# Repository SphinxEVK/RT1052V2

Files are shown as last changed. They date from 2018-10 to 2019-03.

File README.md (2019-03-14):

# RT1052V2

**SphinxEVK**是由SphinxEVK项目成员[StackYuan](https://github.com/StackYuan)设计的，基于I.MXRT1052系列MCU的核心板。板上关键信号(SDRAM, nor flash, sd card)均设计了等长，使用了4-layer，4mil/4mil(线宽/线间距)，直径8mil/14mil(孔/带焊环)的生产工艺，可以被当前主流PCB打样厂生产。

注: 

> 开发板设计了严格的上电时序和电源域，同时兼容RT1052 A0和A1版本。
> 
> 为了减小体积，开发板使用78mil/2.00mm排针设计。如调试飞线感到不便，工程下也提供了标准100mil/2.54mm的IO拓展板：**SphinxEVK_ExtIO.PcbDoc**。

---

**板上资源：**

> 1.预留QSPI nor flash/Hyperflash双焊盘
> 
> 2.预留SDRAM焊盘
> 
> 3.RGB565 CSI接口(异面兼容[龙邱MT9V034](https://item.taobao.com/item.htm?id=562070292609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))
> 
> 4.RGB565 DSI接口
> 
> 5.KSZ8081 ENET PHY
> 
> 6.引出Micro USB(**USB1**) 
> 
> 7.引出UART(**LPUART1**)
> 
> 8.引出SWD(带RST)
> 
> 9.引出SDIO(TF slot)
> 
> 10.引出所有非关键IO

---
**勘误：**

> 1.使用LQ神眼摄像头时，由于IIC线序错误，故使用软件IIC进行初始化
> 
> 2.SD卡可能会出现枚举失败问题，原因是进入高速模式时，主芯片NVCC_SDIO脚不能完成3.3V->1.8V电压的切换。建议暂使用低速模式。
> 
> 3.UART1 RXD未设置上拉，可能在进行ISP模式时由于RT的内部bootloader检测失误，造成USB下载模式不能进入。
> 
---
**SphinxEVK实物图**



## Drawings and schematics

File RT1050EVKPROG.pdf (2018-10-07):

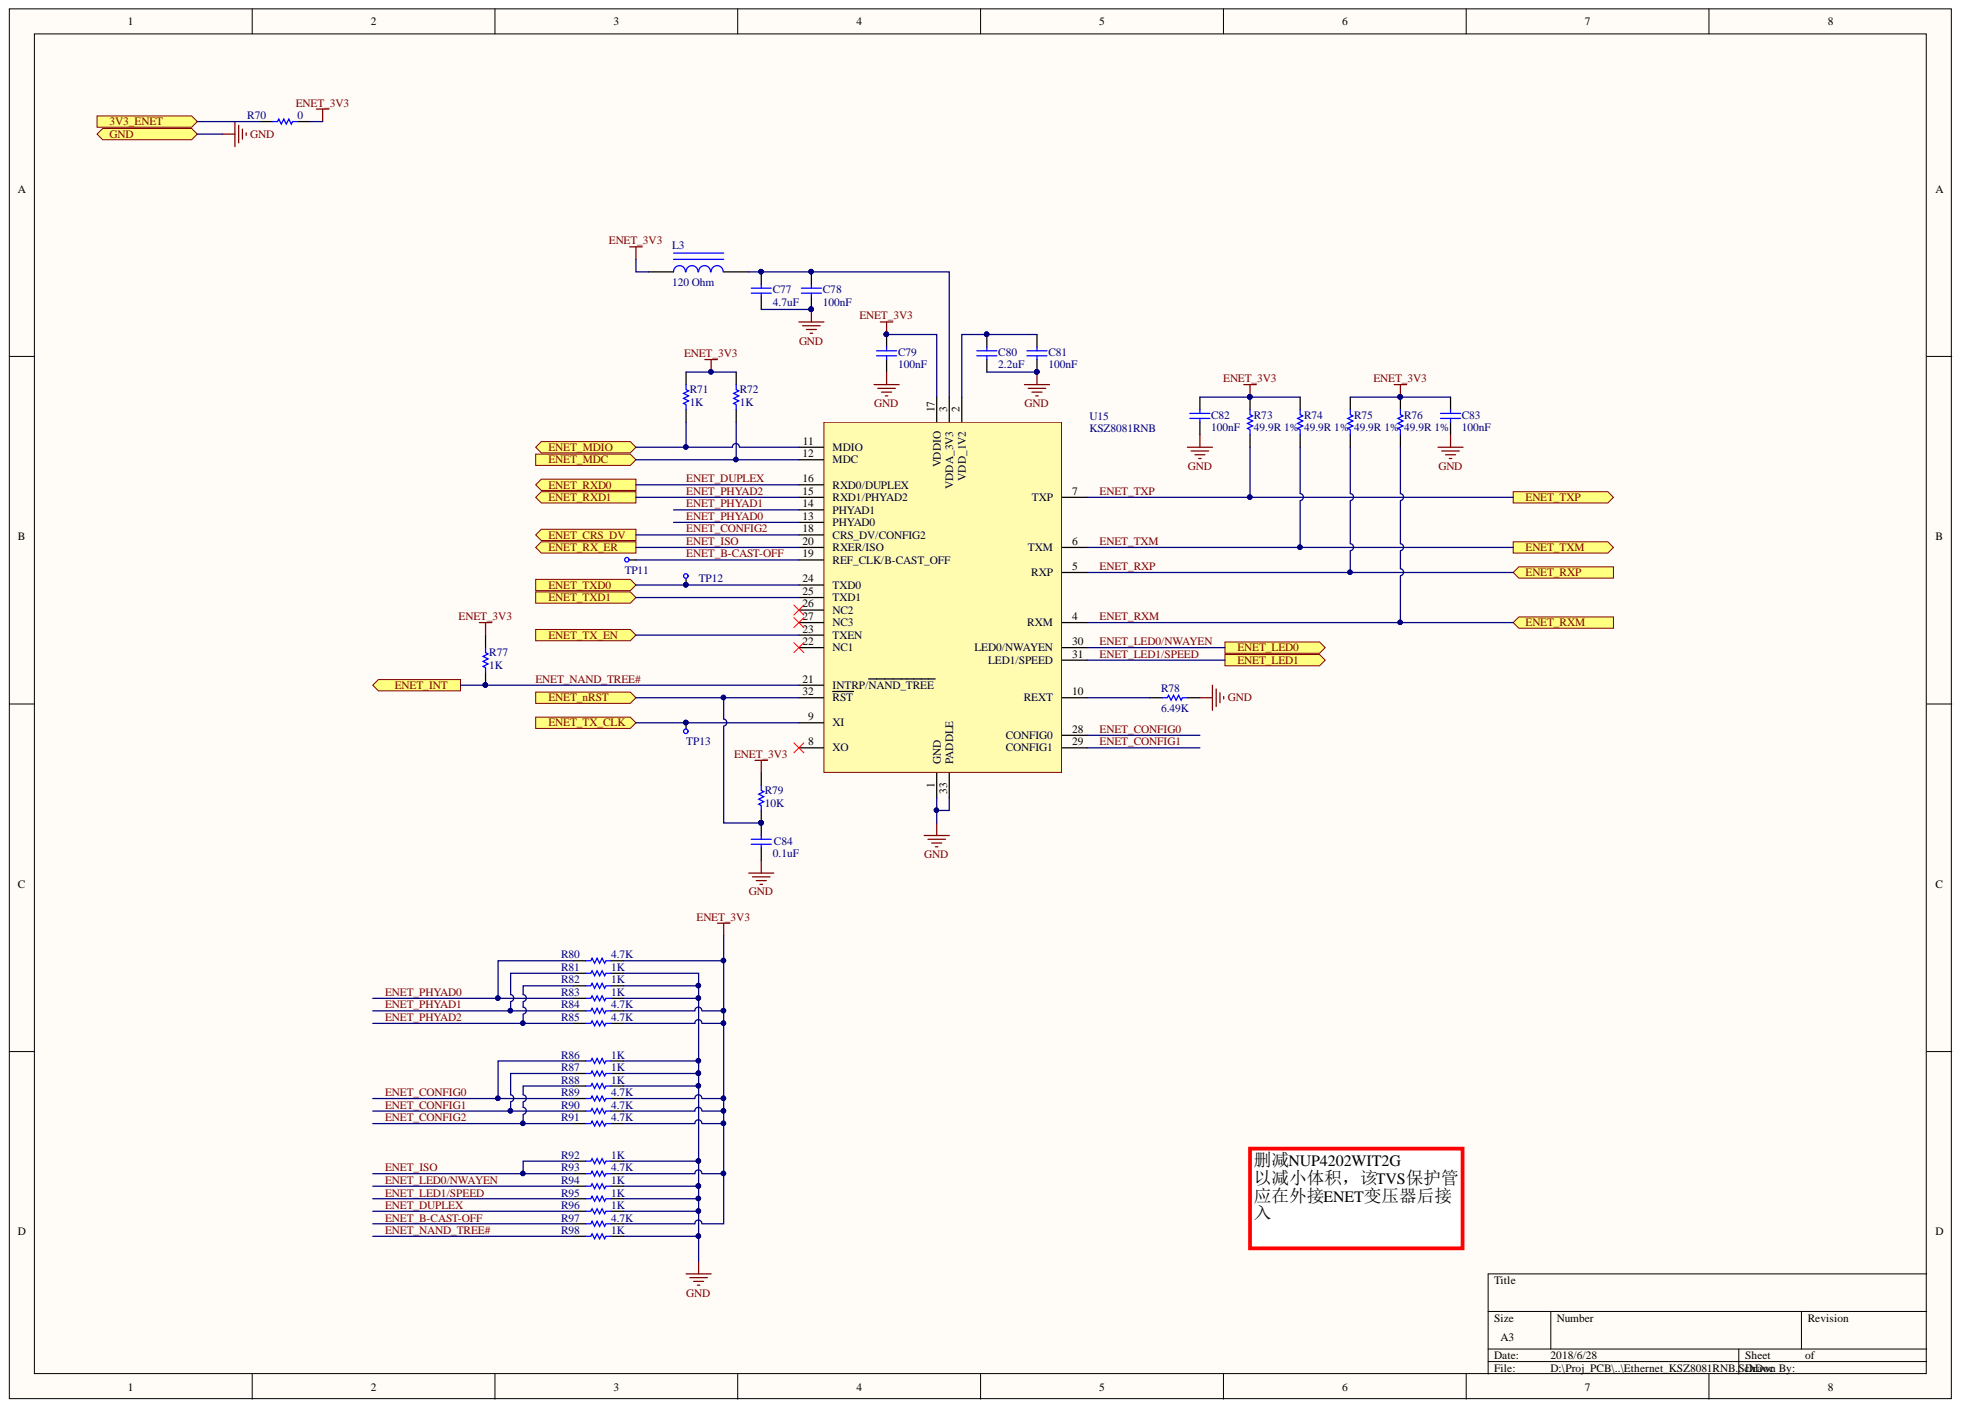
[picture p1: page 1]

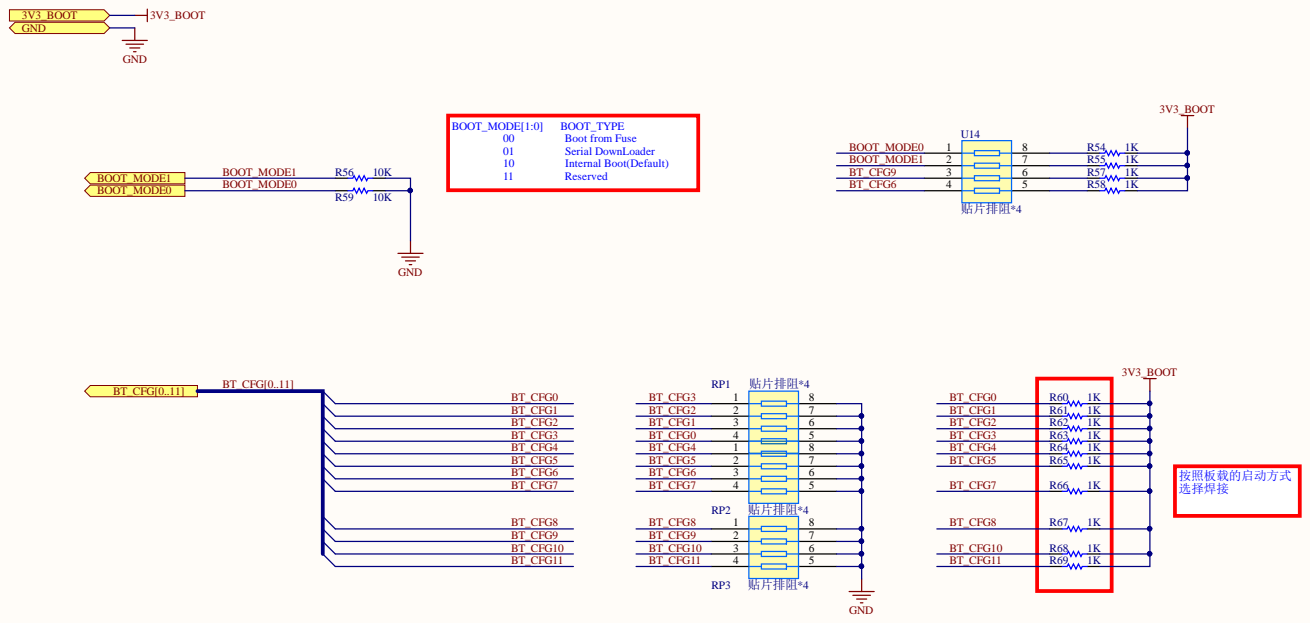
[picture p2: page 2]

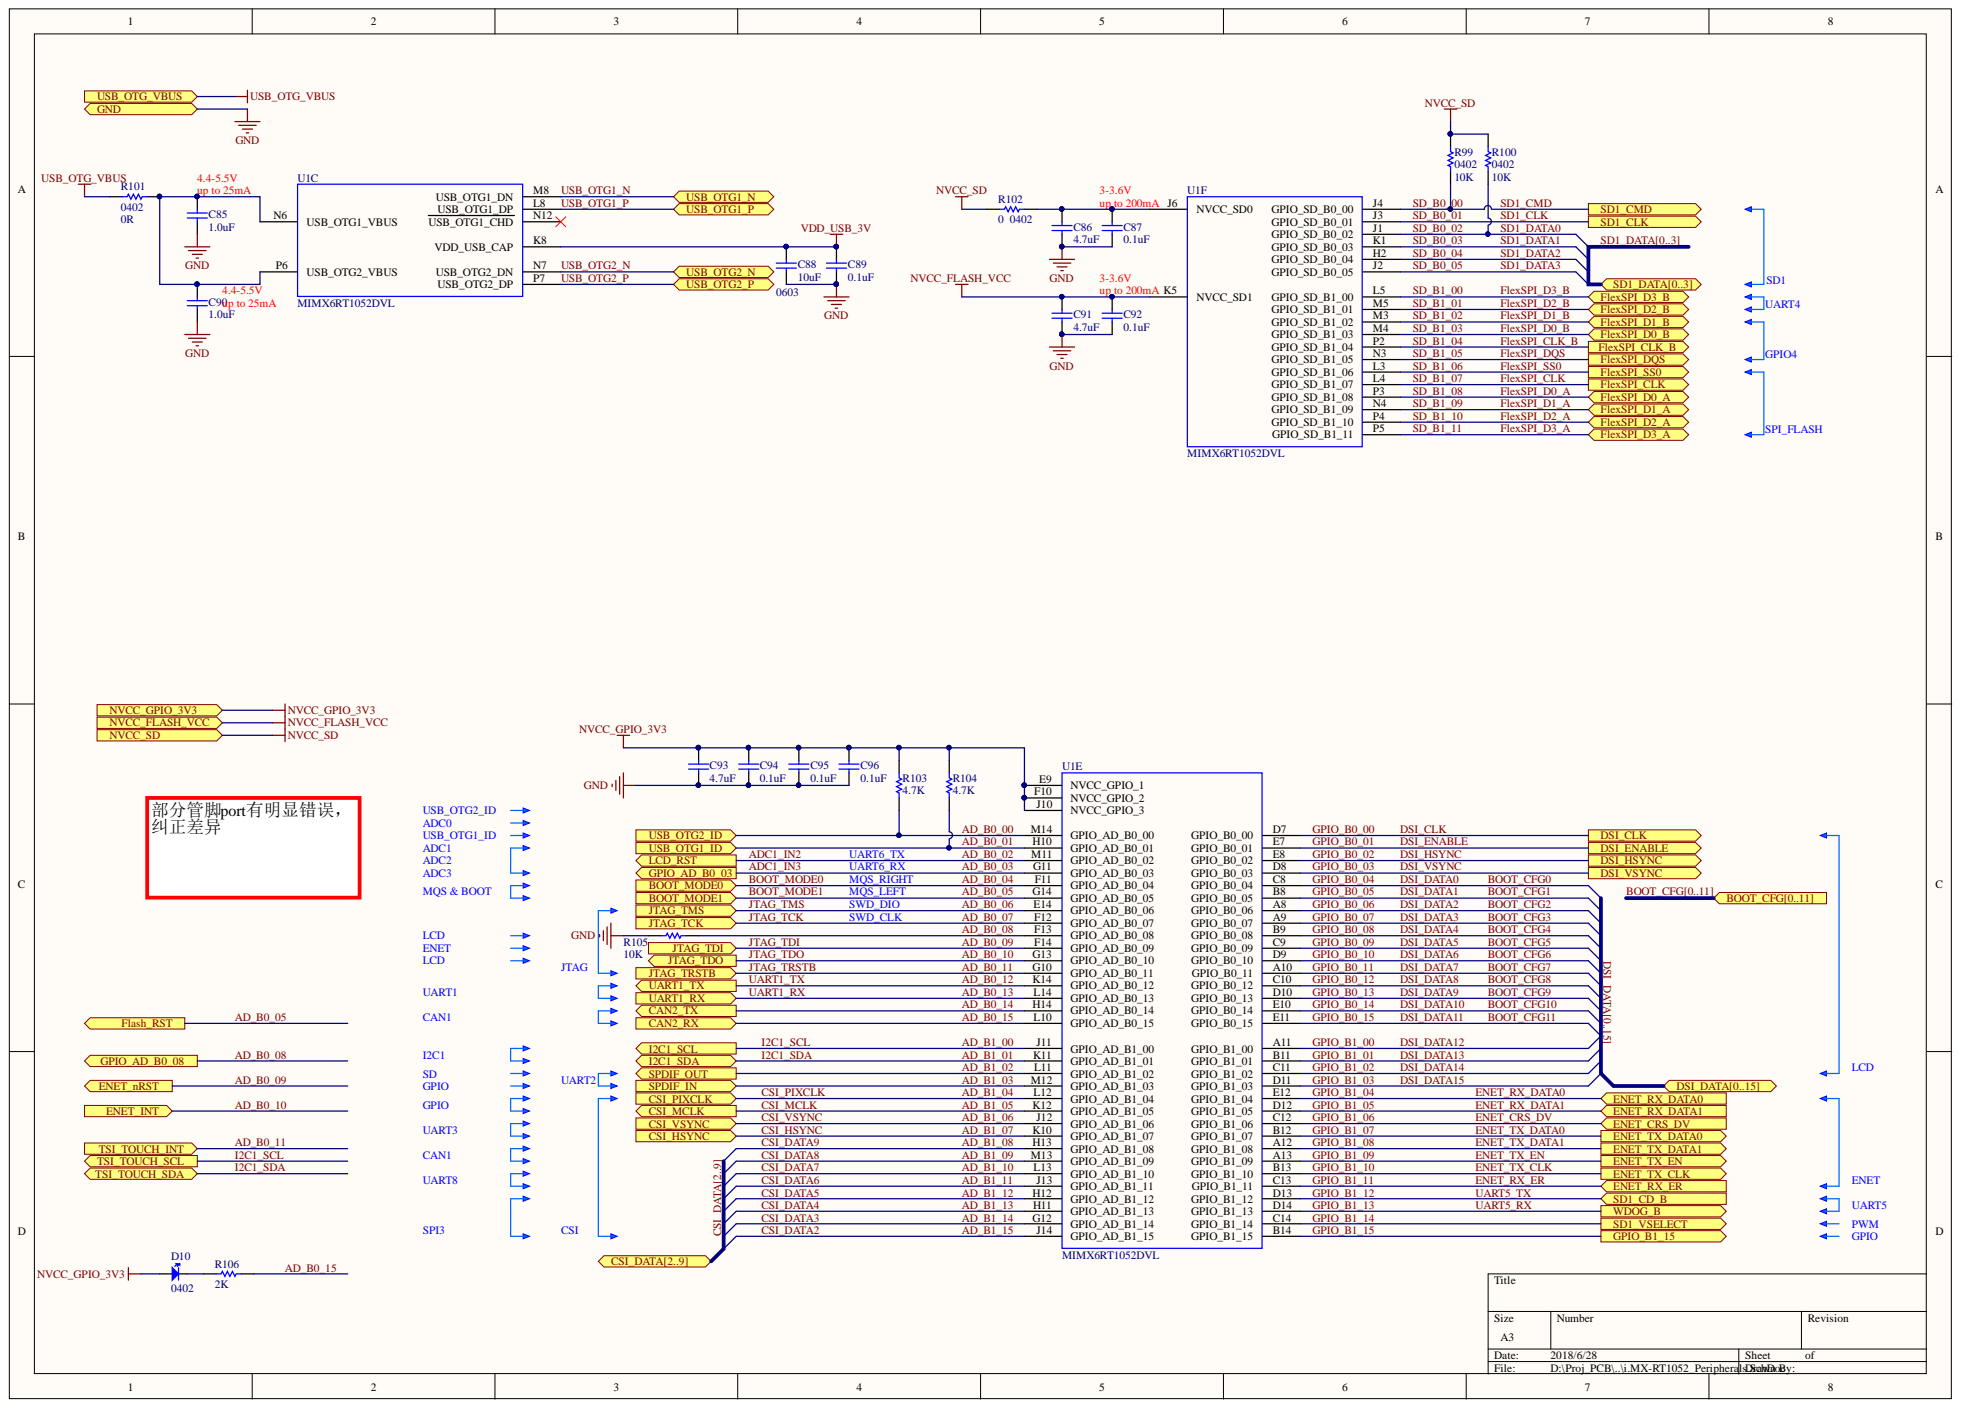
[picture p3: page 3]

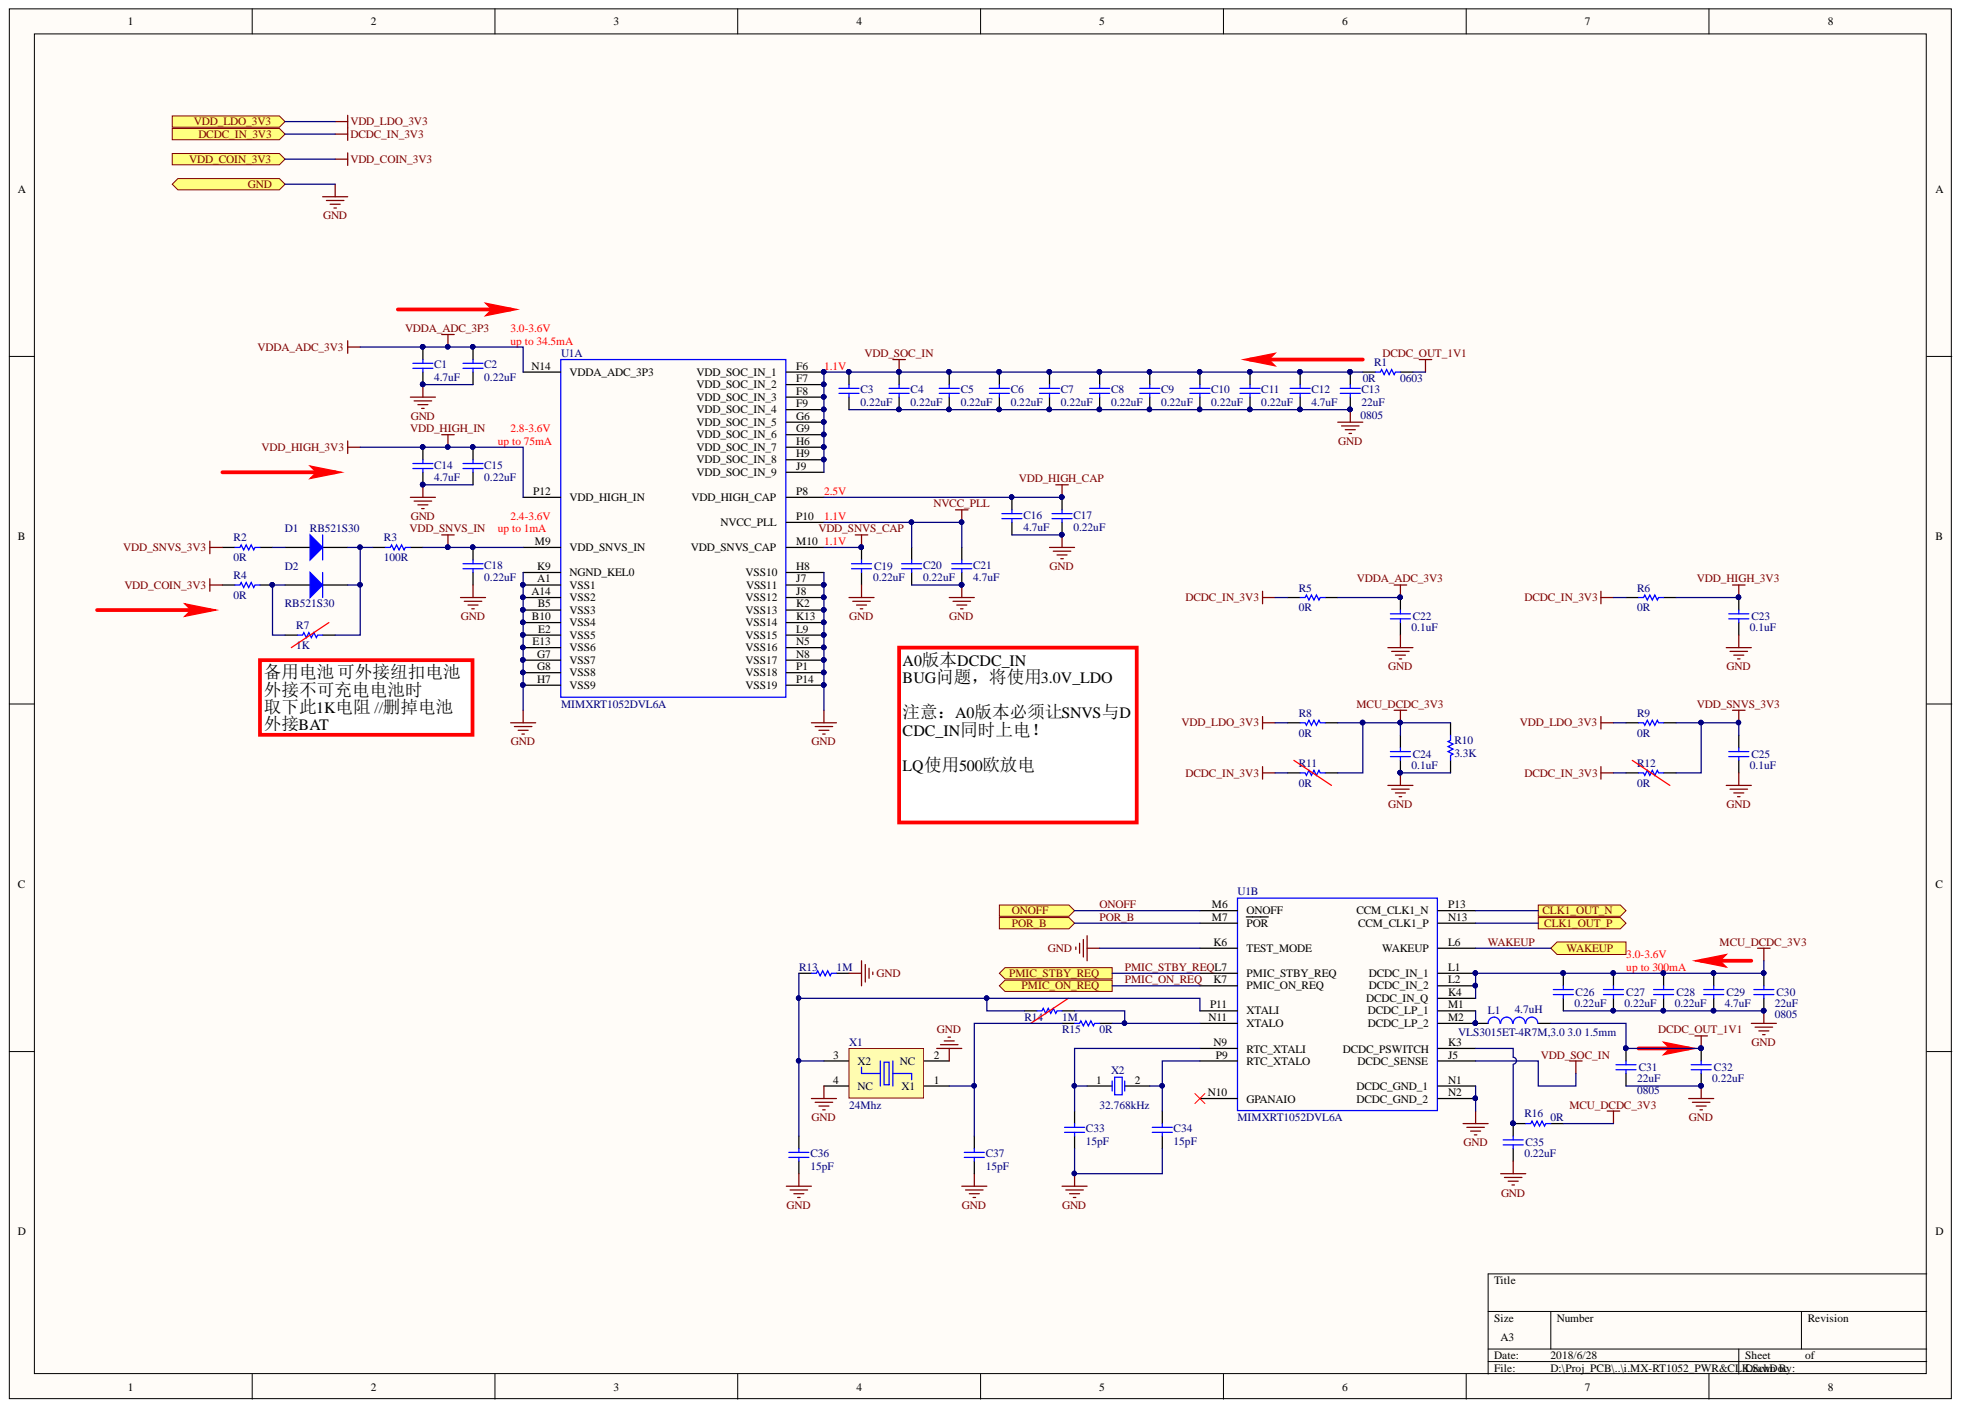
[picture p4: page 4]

C1 | C2
4.7uF

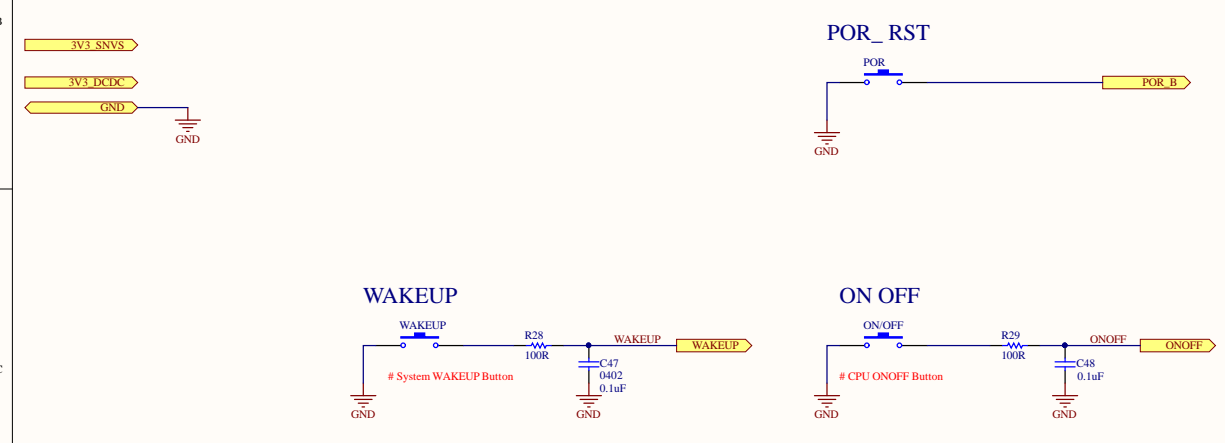
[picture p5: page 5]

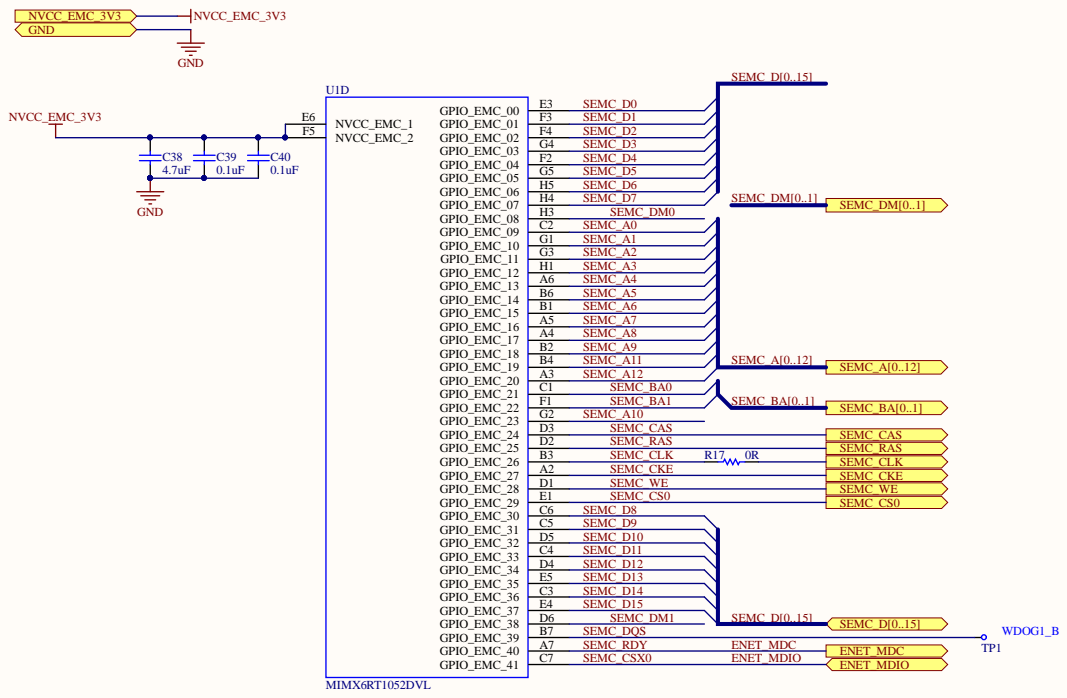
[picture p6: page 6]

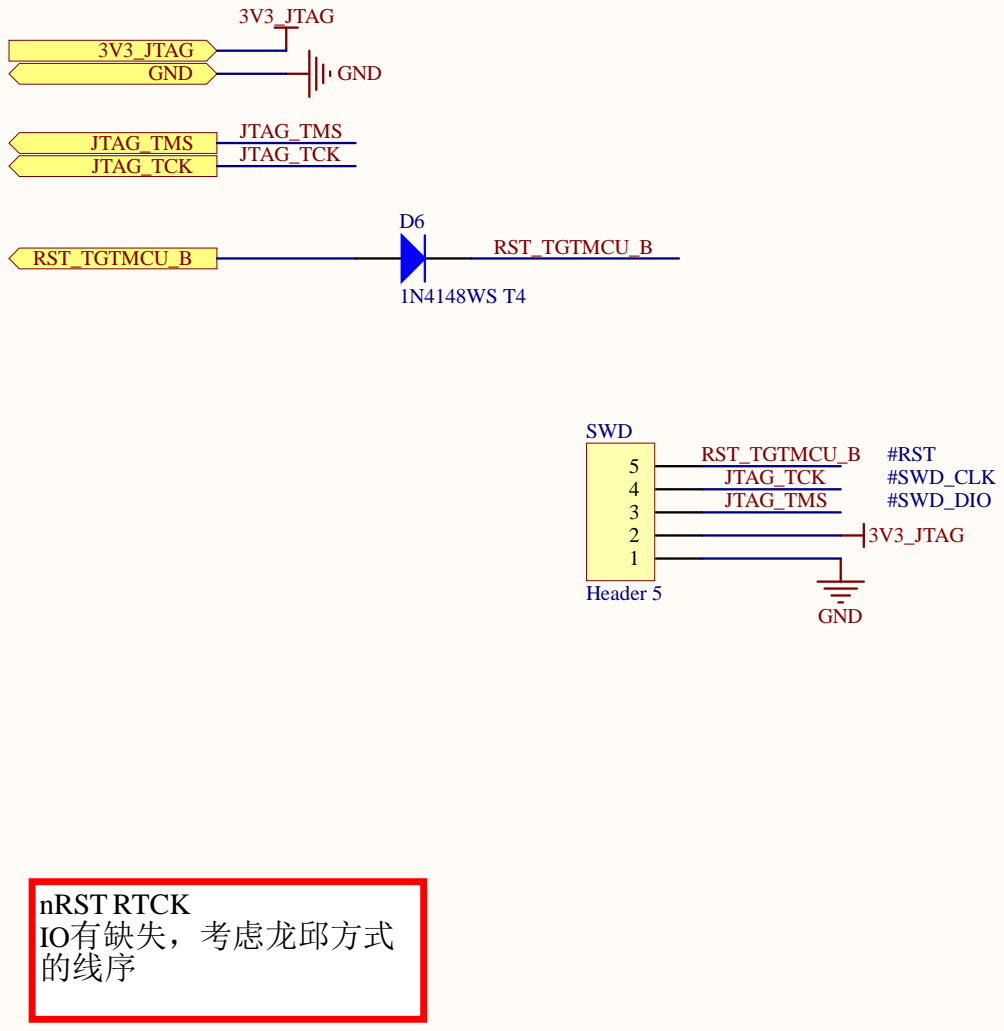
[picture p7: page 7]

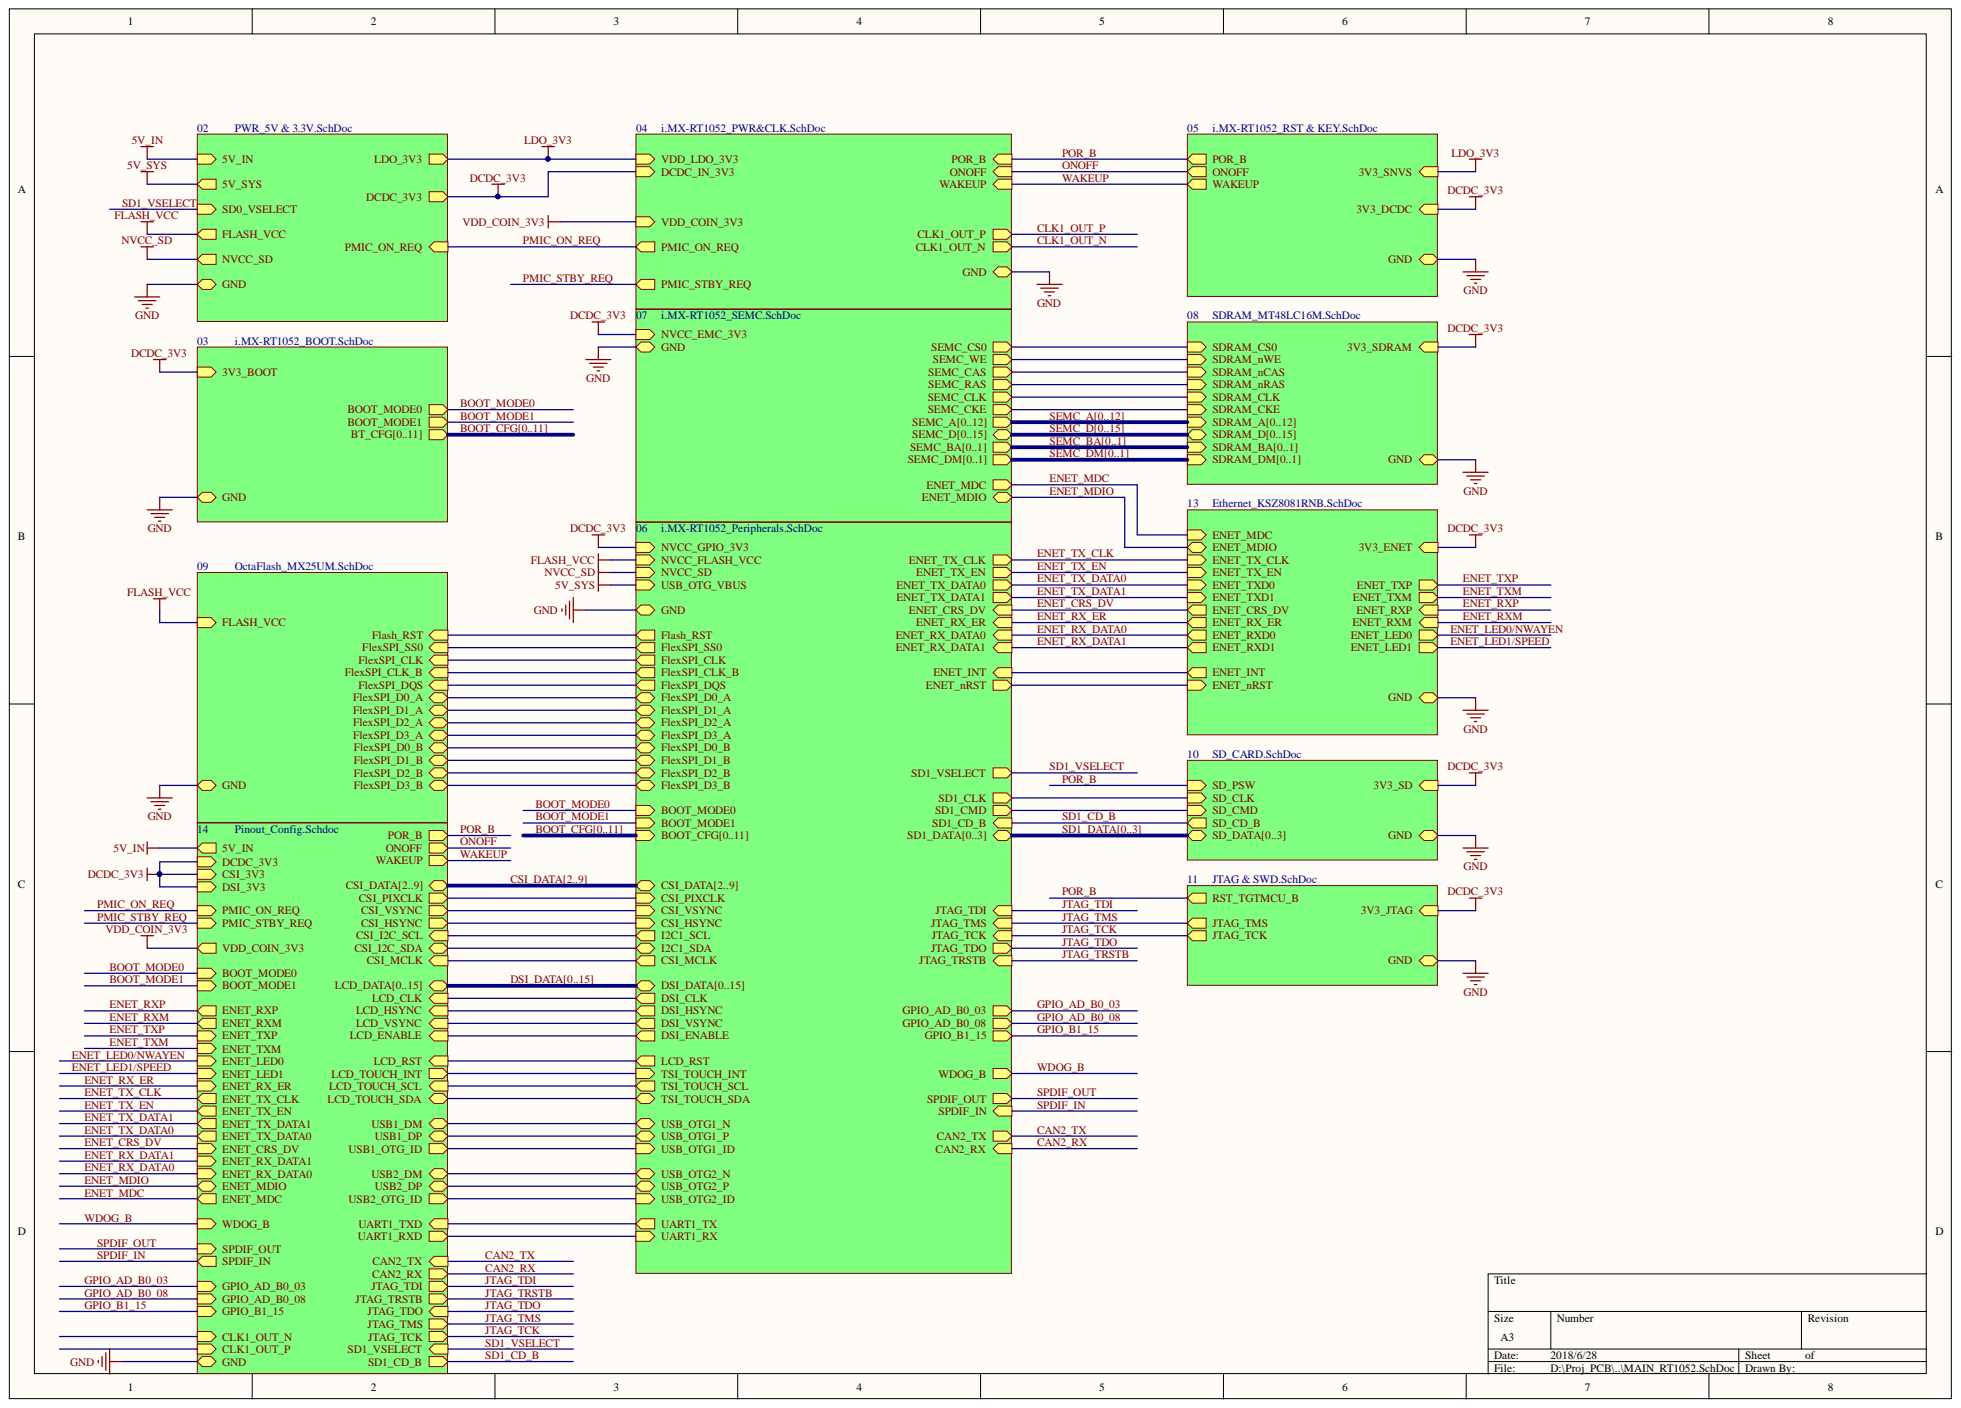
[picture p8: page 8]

BOOT_MODE1 | SEMC_A[0..12]
BOOT_CFG[0..11] | SEMC_D[0..15]

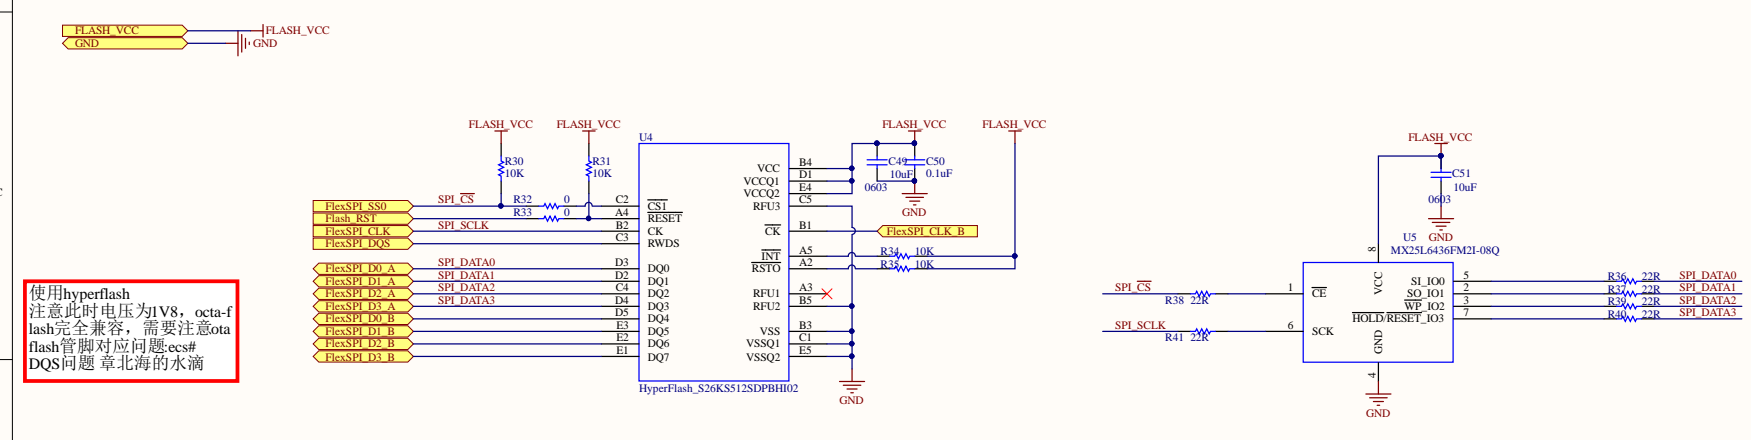
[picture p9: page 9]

使用hype
注意此时电压为
lash完全兼容，需要注意ota flash管脚对应问题:ecs#

B 3
C 1
E 5

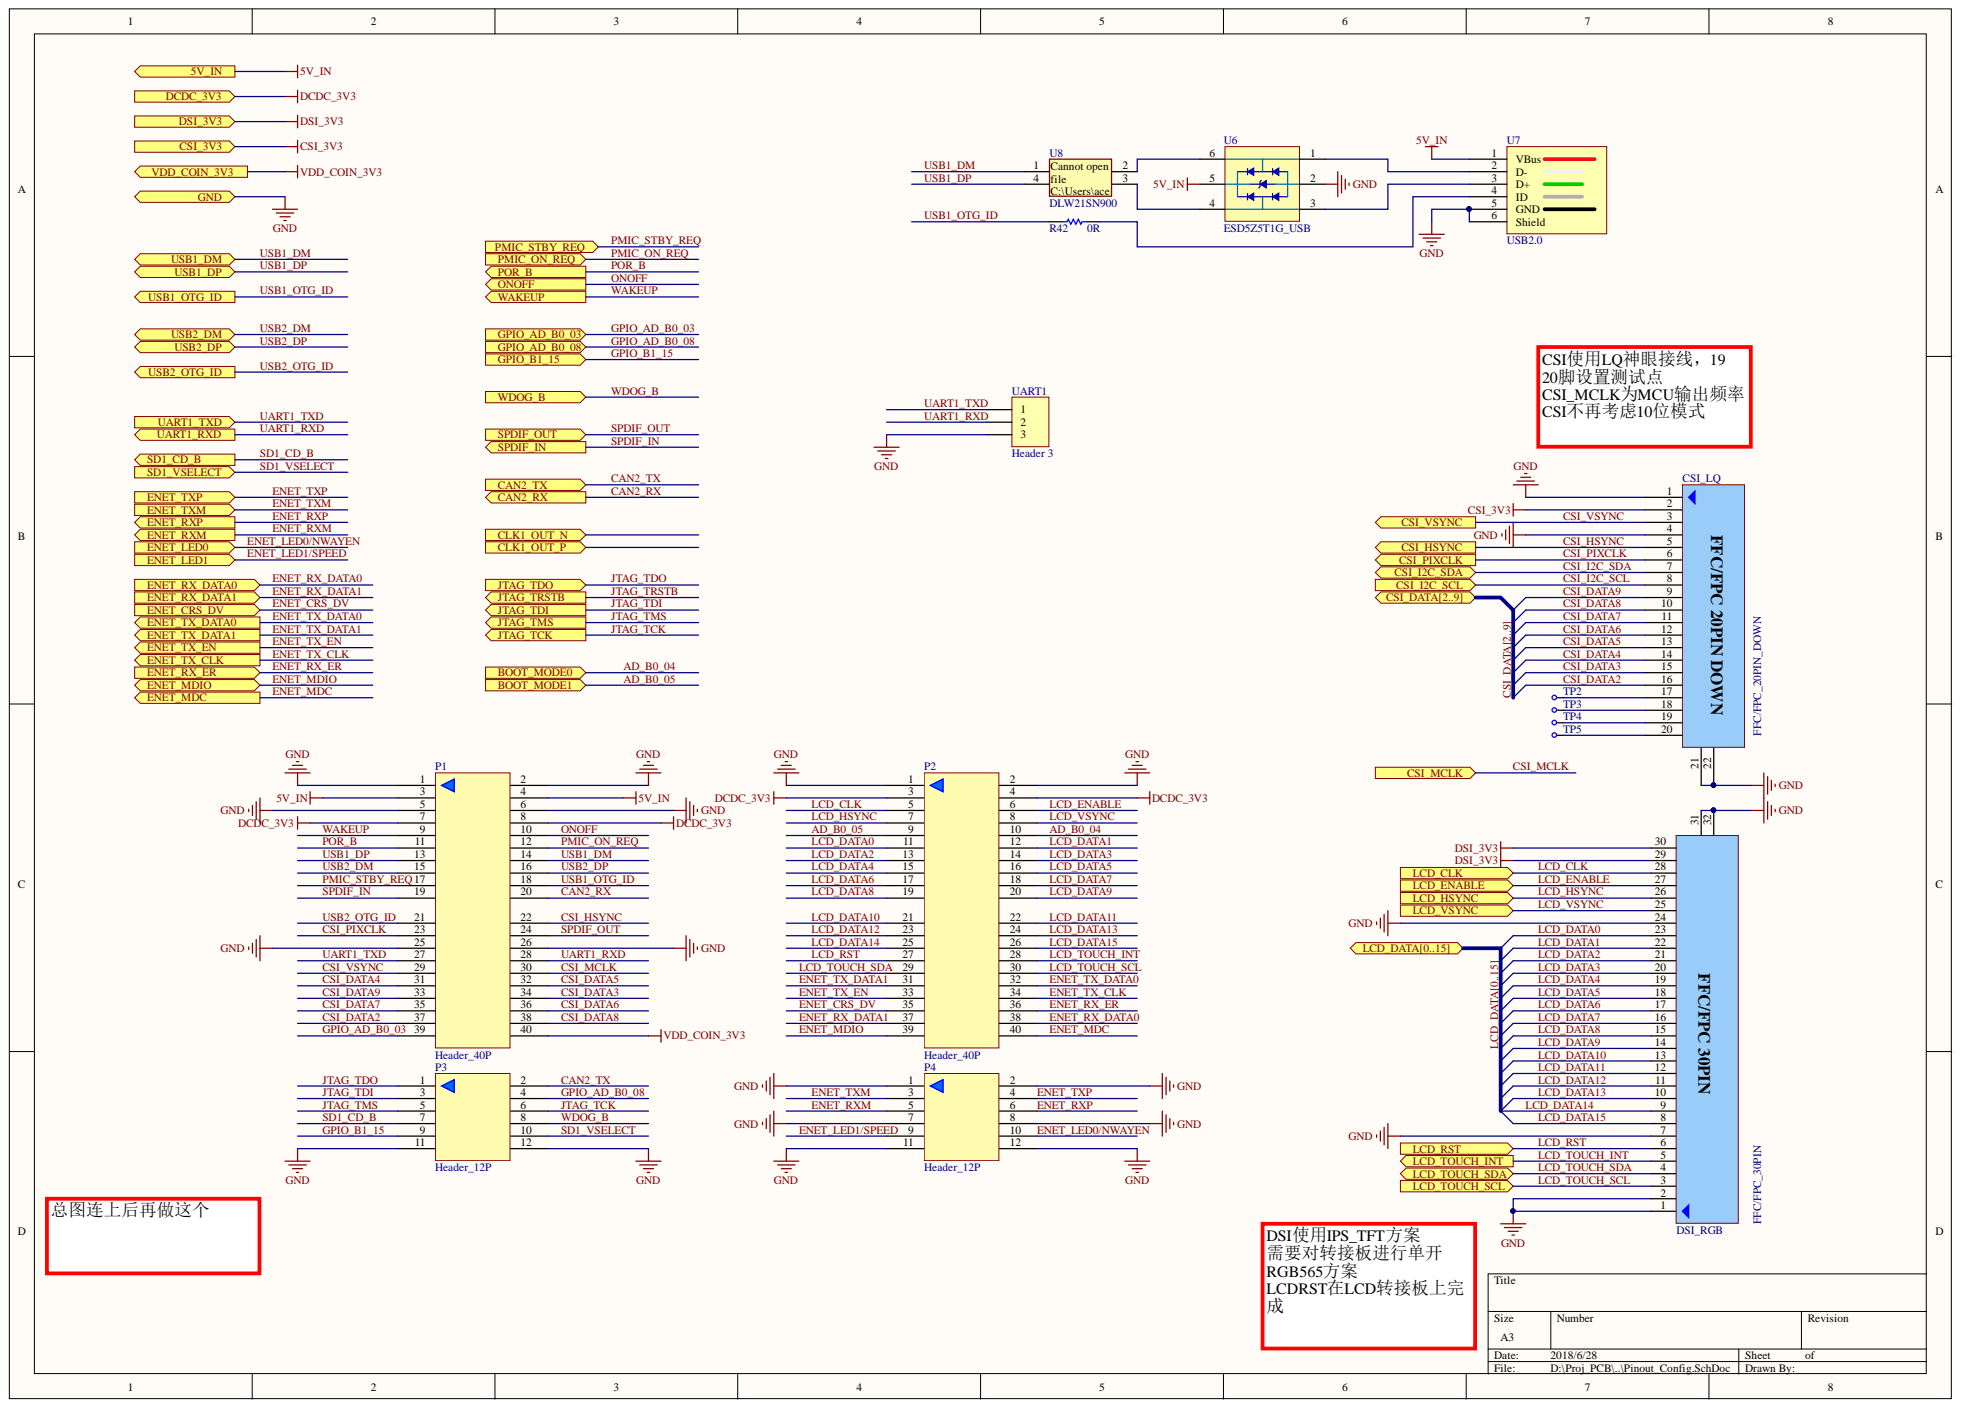
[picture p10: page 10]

WA KE U P 9 | 10 O N OFF | A D_B0_05 9 | 10 A D_B0_04

7 | 8 | | 8 L C D_VSY N C

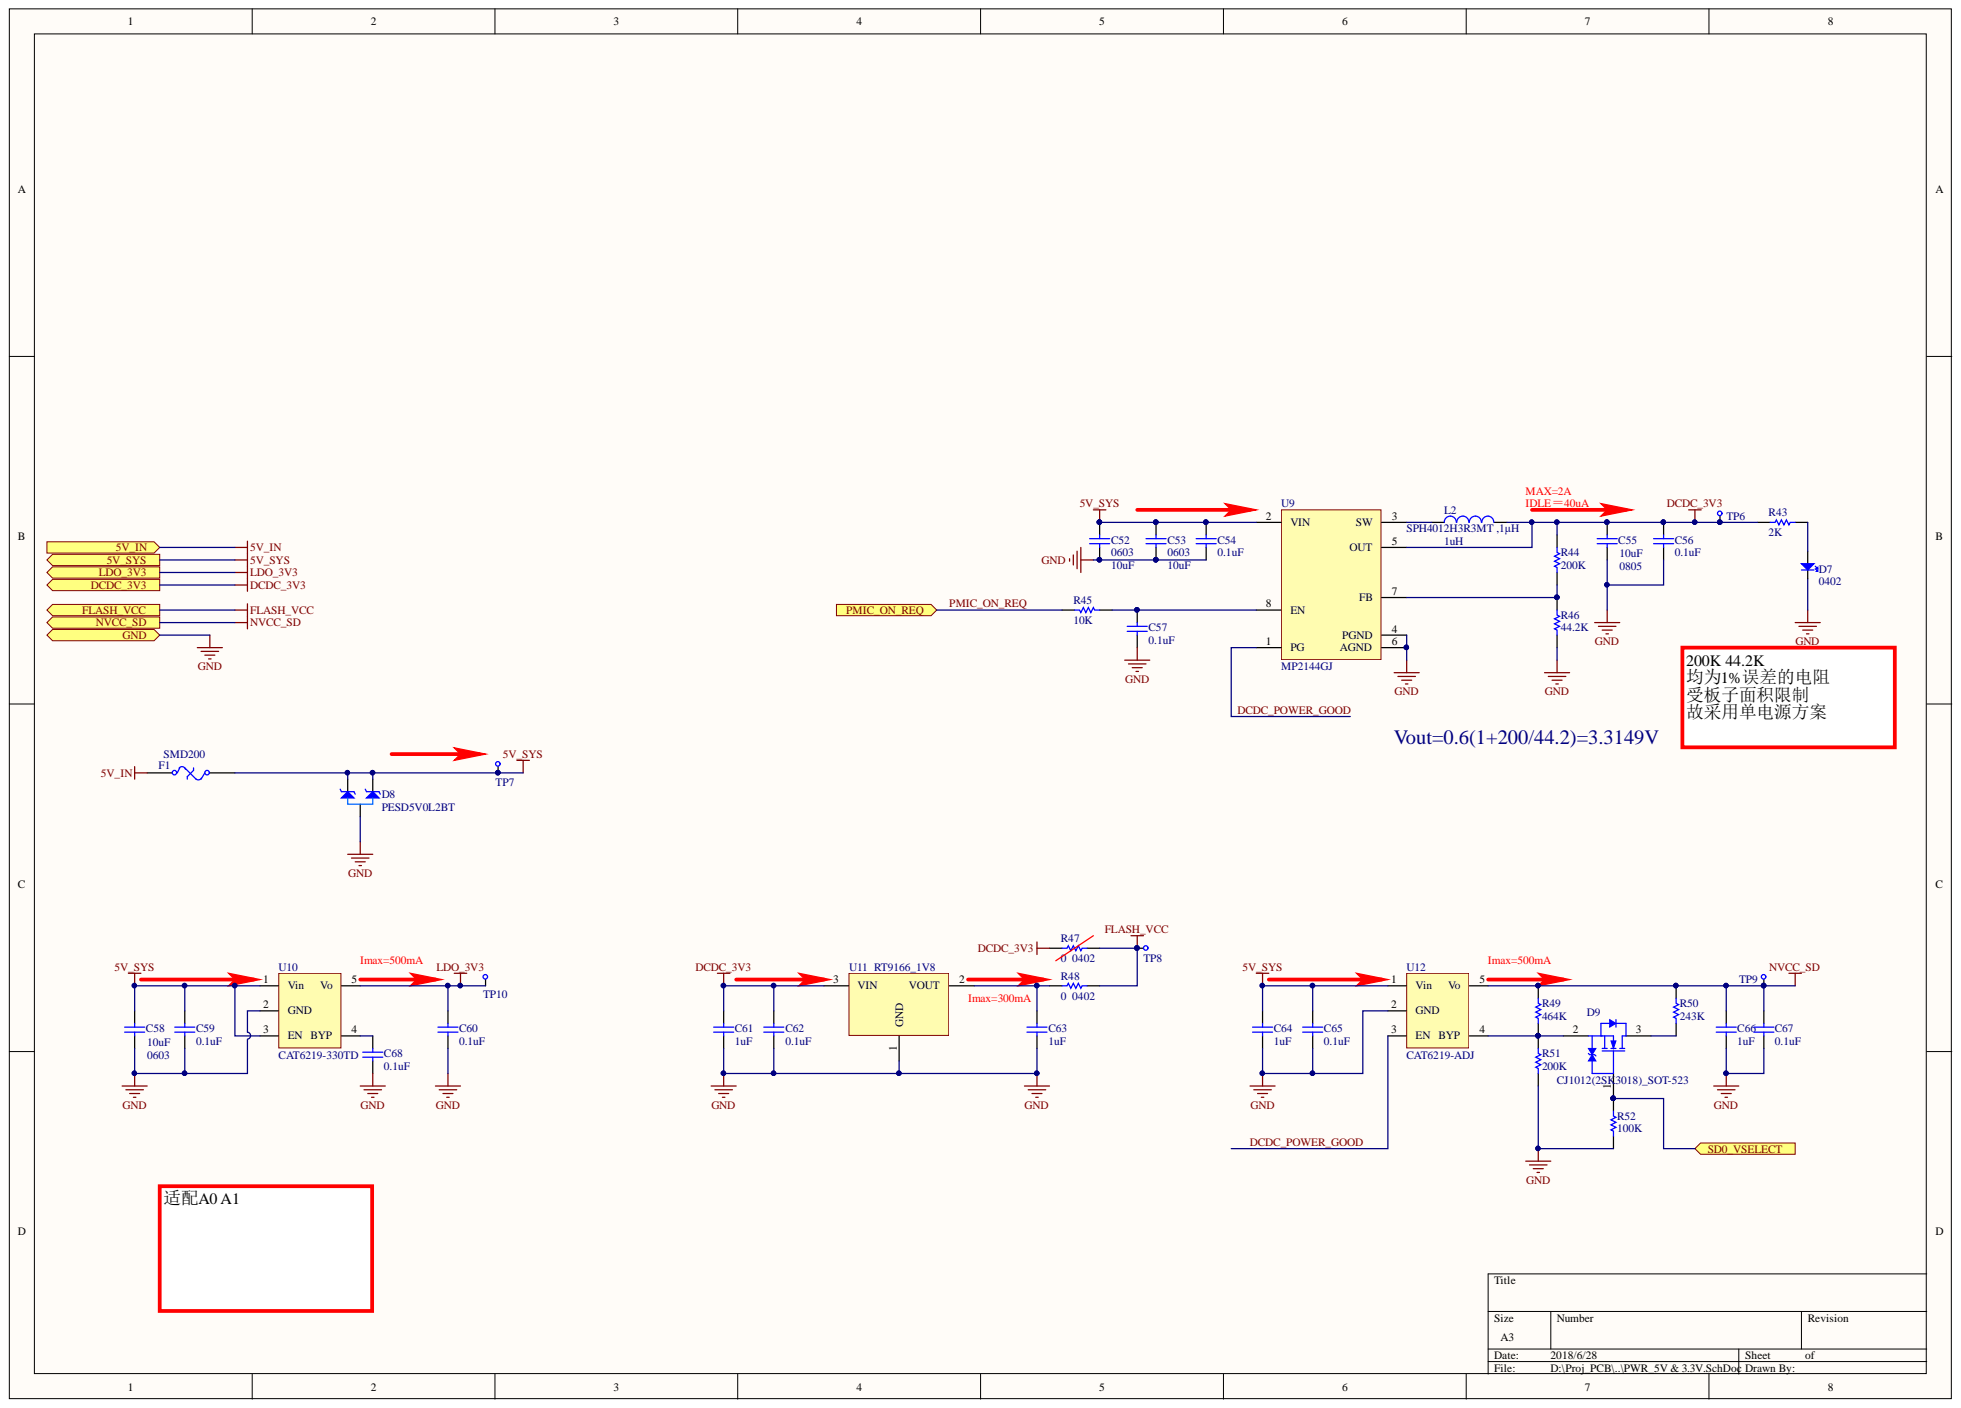
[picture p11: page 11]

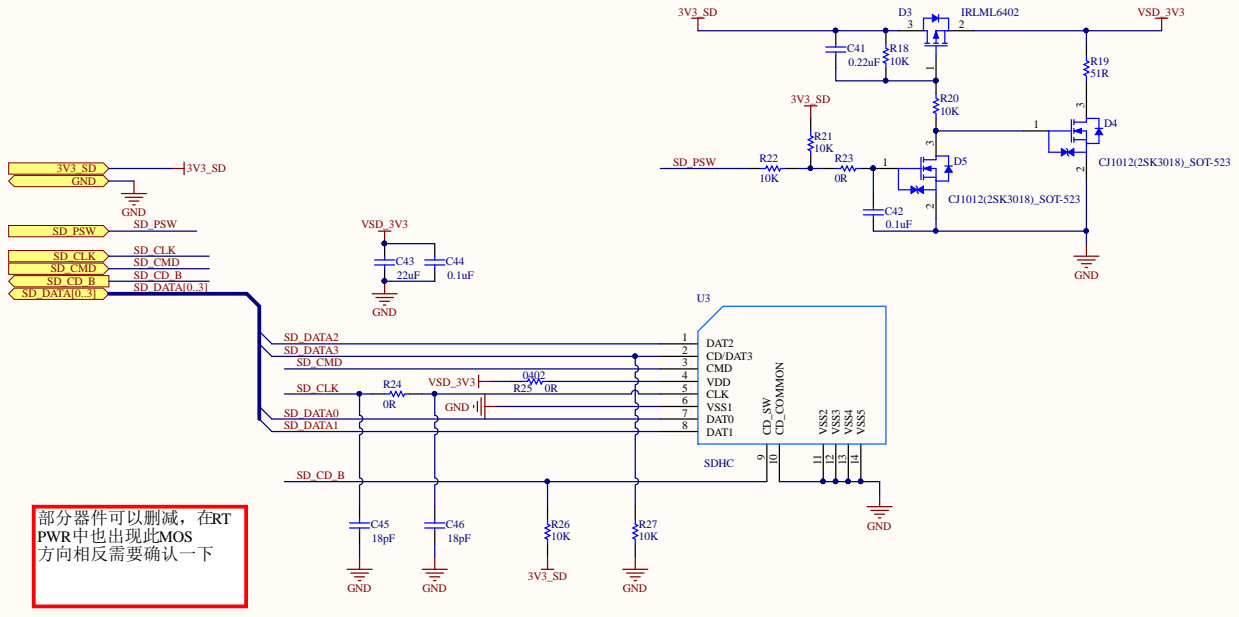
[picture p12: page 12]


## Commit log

2018-10-07 update design files
    [RT1050EVKPROG.PrjPCB]
2018-10-07 fix wrong PCB design file
    [RT1050EVKPROG.PrjPCB]
2018-10-07 added board picture
2018-10-07 added ExtIO design file
    [SphinxEVK_ExtIO.PcbDoc]
2019-03-14 Update README.md
    纠正了readme.md的少许失误，增加了已知勘误部分
